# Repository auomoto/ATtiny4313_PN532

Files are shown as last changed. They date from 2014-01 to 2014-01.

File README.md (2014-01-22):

ATtiny4313_PN532
================
This program controls an Adafruit PN532 RFID/NFC Shield v1.3 from an ATtiny4313.

The target operation is automated filter identification in a telescope filter wheel. Filter holders will have MiFare Classic tags permanently attached. The tags will hold filter identification information.

Ordered three more PN532 shields from Adafruit, 2014-01-16/au
Added ADM1490 (2X) to the schematic for the RS422 serial signal

To-do:
- [ ] Add second controller
- [ ] Add RS-422 transceiver and tie the handshaking lines
- [x] Purchase magnetic sheet for shielding
- [x] Build board holder
- [ ] Build SMD board

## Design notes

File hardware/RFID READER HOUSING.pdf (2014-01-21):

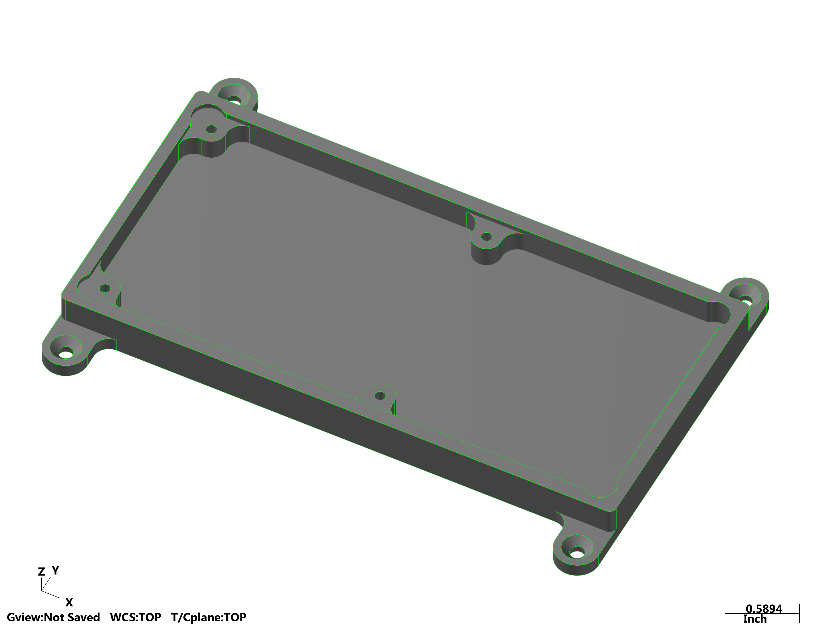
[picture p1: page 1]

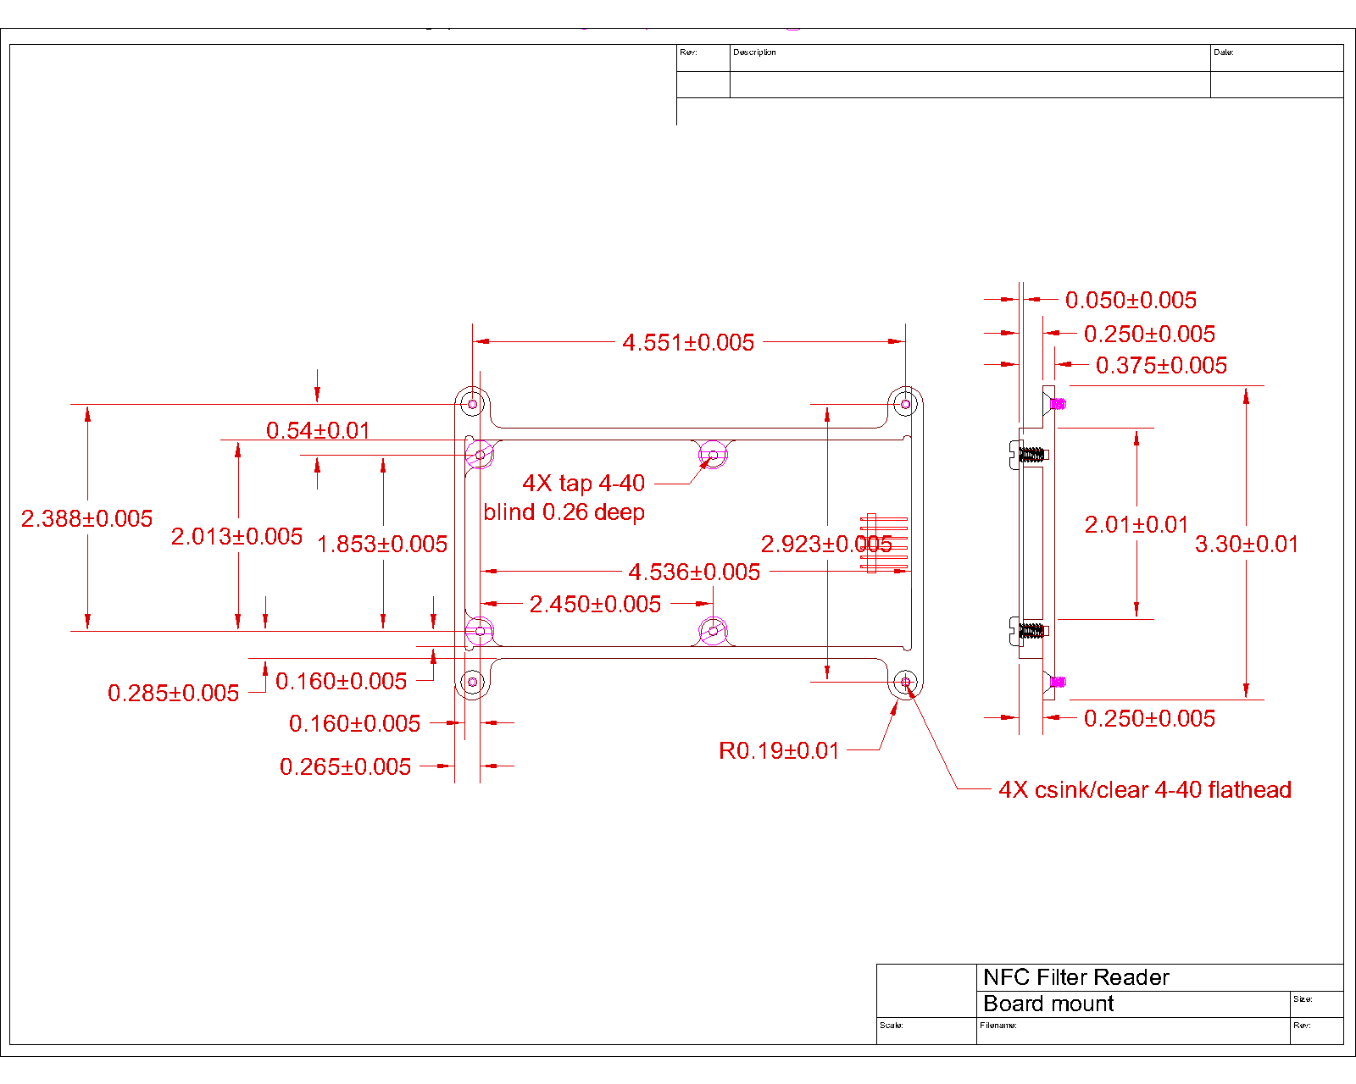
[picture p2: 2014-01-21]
hardware/ATtiny4313_PN532_BoardMount.png

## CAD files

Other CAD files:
hardware/ATtiny4313_PN532_BoardMount.dwg

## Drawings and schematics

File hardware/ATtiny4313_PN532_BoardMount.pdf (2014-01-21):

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

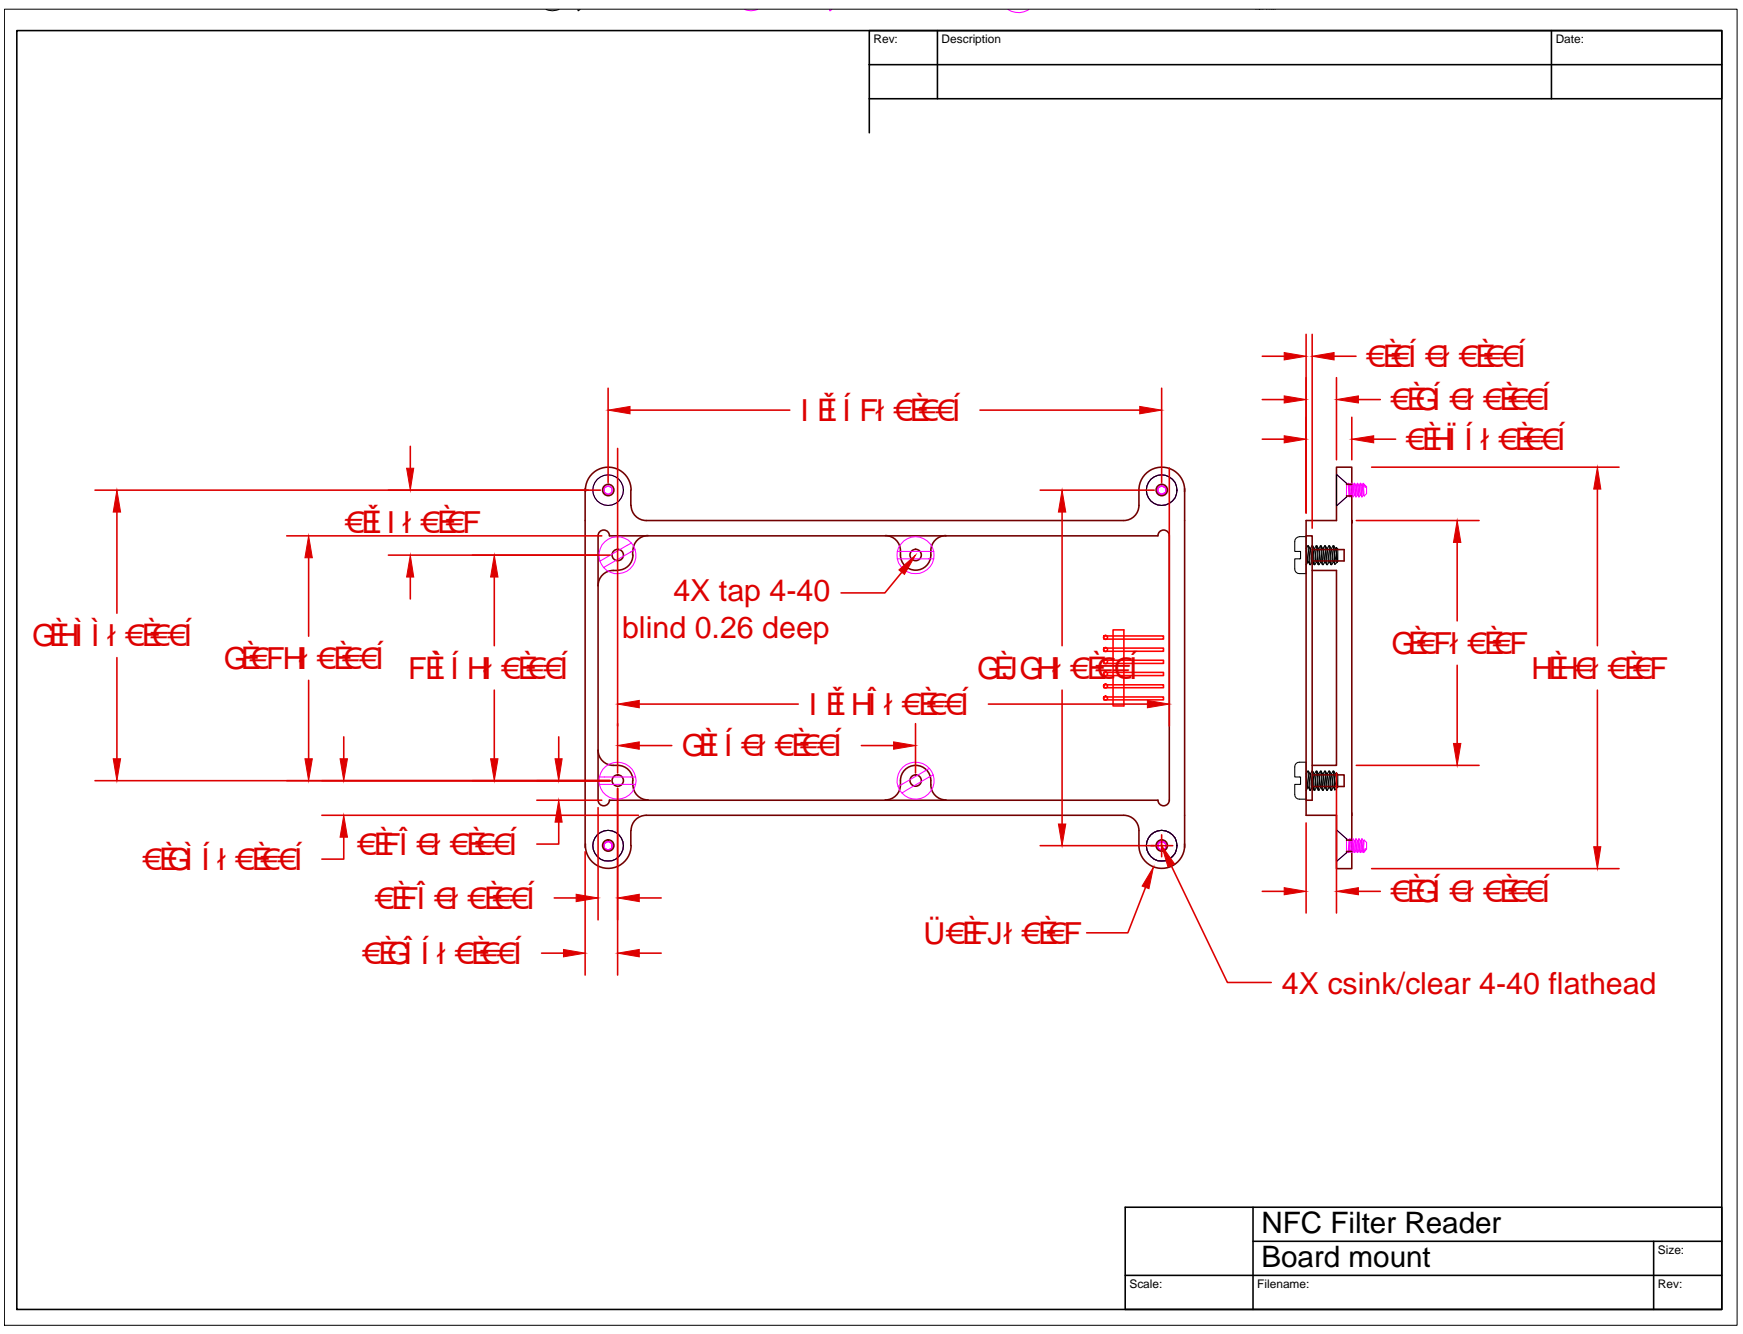
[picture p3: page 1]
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

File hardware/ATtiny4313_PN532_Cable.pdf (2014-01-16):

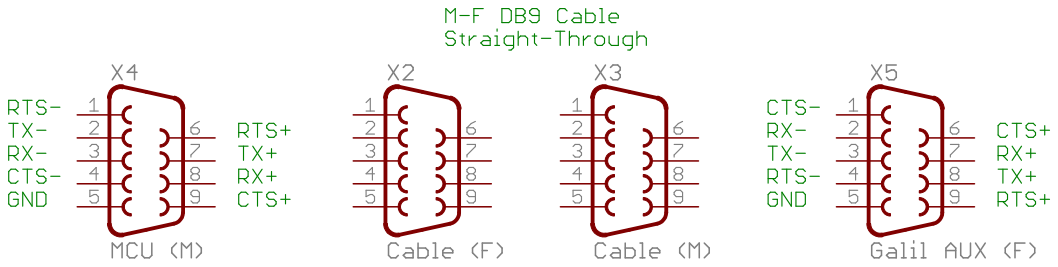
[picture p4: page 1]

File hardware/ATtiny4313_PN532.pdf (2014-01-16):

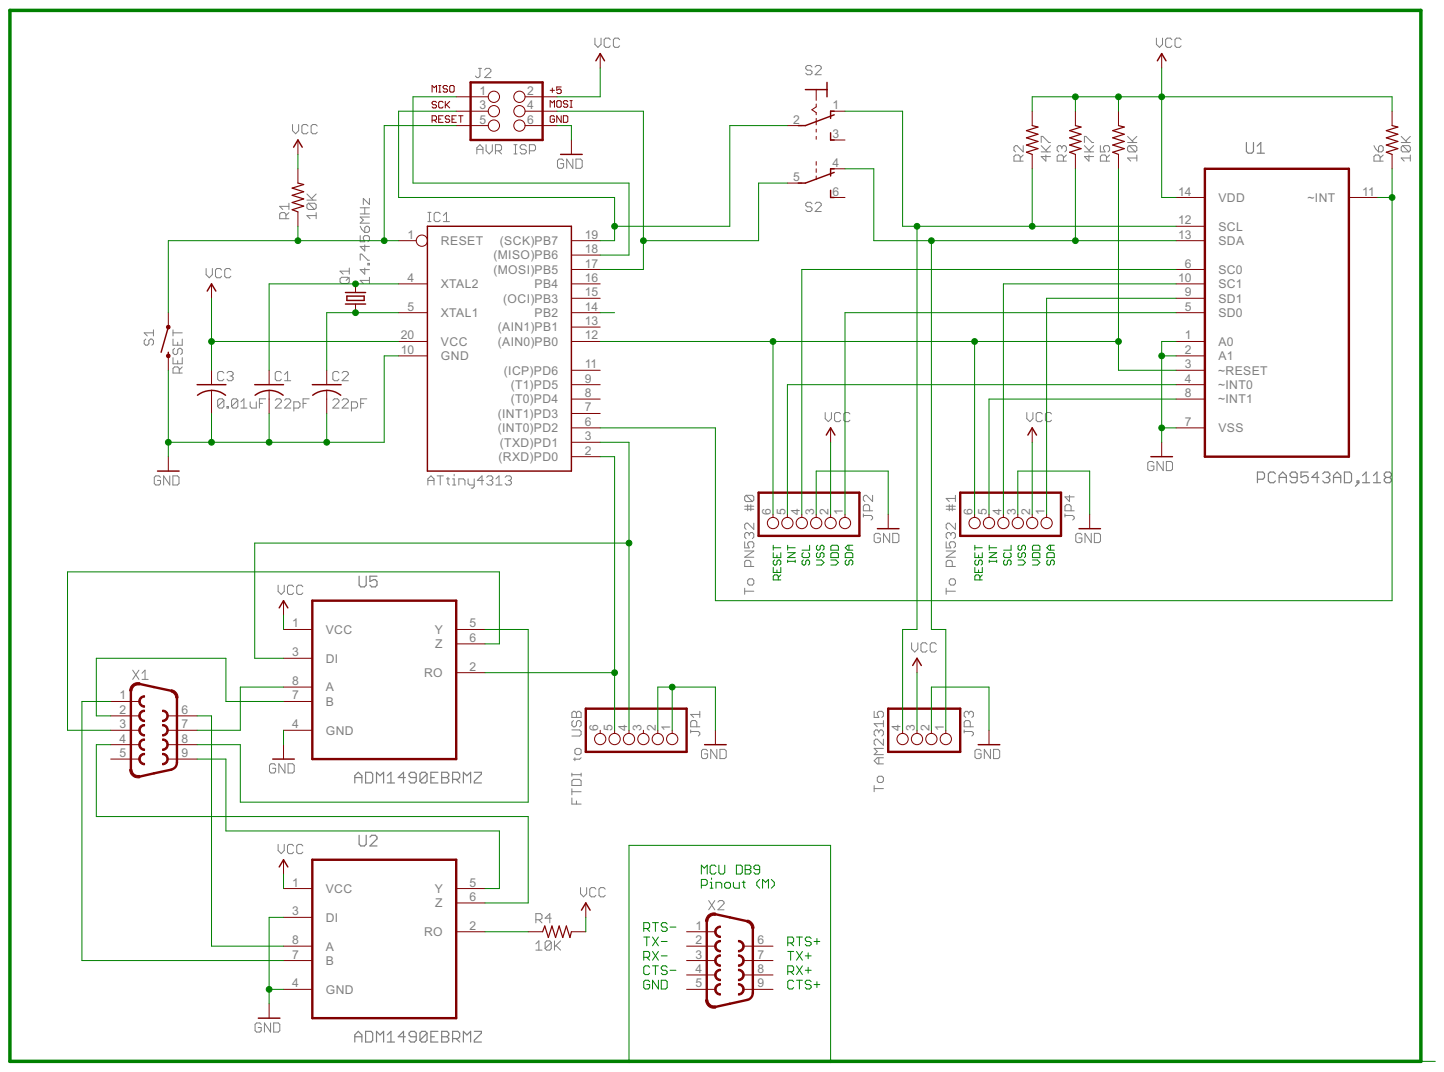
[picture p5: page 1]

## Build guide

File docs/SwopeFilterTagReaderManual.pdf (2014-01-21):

# Swope Filter Tag Reader

## Revisions

Rev | Date | Notes
1.0 | 2014-01-09 | Initial release (au)
1.1 | 2014-01-21 | Added ADM1490 RS-422 transceiver information & more links

## Summary

The Filter Tag Reader reads data from near field communications (NFC) tags. For tags mounted on filter holders this information can identify filter wheel contents. It can also write to the NFC tag.

## Software

Communications is through an RS-422 serial port on the Galil DMC 4080 controller on the Swope IMB. The setup is 19,200 baud, 8-bits, no parity, one stop bit. There is no flow control; the Galil handshaking lines (RTS and CTS) are tied.
Commands sent to the tag reader are one-byte ASCII characters as described below. The command character is echoed. If the command is not ‘w’ then the echoed command character is followed by “\r\n”. If there is returned information (the tag data, status information, or an error code) that information is sent and followed by another “\r\n”. Finally the prompt character ‘>’ is sent.

### Commands

Command | Name | Details
0 or 1 | Select wheel | These are ASCII characters 0 (numeral zero, not oh) and 1 (numeral one, not ell). Subsequent commands will reference the selected filter wheel, 0 or 1.
i | Tag ID | Prints the 32-bit MiFare tag ID in hex. This probably isn’t a useful number to know but if a reply is returned you know it’s a MiFare Classic tag.
r | Read tag | If a tag is present 32 bytes are returned. A brand-new blank tag will likely contain zeros (0x00, not the ASCII numeral). For prepared tags, an end-of-string byte (\0) is not necessarily included in the 32 bytes.
R | Reset | Reboots the microcontroller and resets the hardware. Total time should be less than one second and you’ll see a “WD\r\n>” returned. The “WD” refers to a watchdog reset, which can happen only with this command (the watchdog timer is disabled except for this reset function). The input stream to the tag reader is cleared on reboot so commands sent immediately following the “R” and before the WD response will be lost.
s | status | Prints system status information. In order, the returned items are the program name (“FIlter_Reader”), this software version number (yyyymmdd), firmware version of the selected tag reader (if it’s “X.X” and not “1.6” then no tag reader is present), and the contents of the program status byte. Bit 0 of the status byte shows the currently selected wheel number (0 or 1). The other seven bytes are program error codes. If they’re not all zeros (that is, if the status byte is not 0x00 or 0x01), you should probably try a read command (‘r’) or do a reset (‘R’ command)..
w | Write tag | This command writes the following 32 bytes to the tag. A carriage return (\r) terminates data entry if you have fewer than 32 bytes to write. The \r will not be included in the 32 bytes. The remainder of the 32 bytes will be padded with spaces (‘ ‘ or 0x20). Example: wH-Beta Filter\r will write “H-beta Filter” padded with spaces into the tag.
\r (CR) | No-op | Sending a carriage return will return the command prompt string “\r\n>”

### Errors

The tag reader may reply with an error code. The error code format is “\r\nENN\r\n>” where NN are ASCII numerals as described below. Note that the “\r\n>” sequence right after ENN distinguishes this from a read-back of valid tag data which always returns 32 bytes. Except for errors 10, 11, and 99, you’ll need to look at the firmware source code for why the problem occurred.

Code | Meaning
E99 | Not a command (the byte sent was not recognized as a command)
E10 | No tag or an unrecognized tag at wheel 0
E11 | No tag or an unrecognized tag at wheel 1
E20 | Problem writing to tag on wheel 0
E21 | Problem writing to tag on wheel 1
E80 | Initialization error on tag reader for wheel 0
E81 | Initialization error on tag reader for wheel 1

### Reboot transmissions

The tag reader will send these messages without being commanded. All of these happen after a reboot and all are followed by a “\r\n>” sequence.

Message | Meaning
BO | Reboot after power brown-out (supply voltage under 2.7VDC)
PB | Pushbutton reset (the button on the MCU hardware was pushed)
PU | Power up start
WD | Watchdog reset (only happens with the R command)

## Firmware

### Source Code

The firmware source code resides in a GitHub repository. (https://github.com/auomoto/ATtiny4313_PN532) The program is for an Atmel ATtiny4313, compiles under avr-gcc (Windows version), and uses avr-gcc specific macros.

### Status Register

The contents of an 8-bit status register is the last item printed on a status command (letter s). Bit 0 of this byte contains the current selected filter wheel (from the 0 or 1 commands). The other seven bits contain error codes that we expect only rarely. These might be caused by a hardware failure, loose wire connection, or a bad tag. If any of bits 1-7 are not zero, try a Reset (‘R’) command to see if that clears the condition. These can be confusing in the sense that you cannot tell which tag reader (or both) caused the error.

Bit 0 - Indicates which filter wheel reader is connected.
Bit 1 - recvAck error. The reader did not send an ACK frame after a command.
Bit 2 - Firmware version error. The reader firmware wasn’t read or is wrong.
Bit 3 - authenticateBlock error. The password for the block is not 0xFFFFFFFFFFFF. Bit 4 - readBlock error. A problem reading one or both data blocks.
Bit 5 - writeBlock error. A problem writing a block.
Bit 6 - sendCmdAck error. A command transmission / reception error.
Bit 7 - init_pn531 error. Initialization (samconfig or rfconfig error).

## Hardware

### Tags

We use Mifare (http://en.wikipedia.org/wiki/MIFARE) Classic 13.56 MHz tags. They have a few hundred bytes of usable storage memory although we’re only using 32 bytes and come in a wide variety of shapes, sizes, and colors. Because our filter frames are made of aluminum, we need to use “anti-metal” tags, which have a ferrous layer isolating the tag from the underlying aluminum.
You should get unformatted tags (not preformatted NDEF tags).
These tags come from the factory with authentication key (password) of 0xFFFFFFFFFFFF and we do not change this.

### Tag reader

The NFC tag reader controller is the NXP PN532 chip. (http://www.nxp.com/products/interface_and_connectivity/nfc_contactless_reader_ics/PN5321A3HN.html) We chose an Adafruit-branded “shield” (https://www.adafruit.com/products/789) version of the microBuilder board. (http://www.microbuilder.eu/Projects/PN532) This board has a built-in antenna and runs on 5 VDC.

The PN532 can communicate via SPI, I2C, or serial interfaces. We chose I2C (TWI). In retrospect, it might’ve been easier to use SPI for this project since the PN532 has only one fixed I2C address option, which makes using two of them more difficult.

### MCU

The MCU is an Atmel ATtiny4313. (http://www.atmel.com/images/doc8246.pdf) This chip has a hardware UART for serial communications to the Galil controller. We’re using a 14.7456 MHz crystal that allows us to choose common serial baud rates.

### Bus switch

Since all PN532 boards have identical I2C addresses we will use the PCA9543AD (http://www.nxp.com/documents/data_sheet/PCA9543A_43B_43C.pdf) I2C bus switch to select which of the two boards we want.

### RS-422 conversion

To convert the RS-422 signals on the Galil controller to TTL serial levels, we’ll use two ADM1490 (http://www.analog.com/en/interface-isolation/rs-485-rs-422/adm1490e/products/product.html) transceivers. Each ADM1490 has one transmitter and one receiver. We need two because the Galil RS-422 interface requires hardware handshaking with the RTS and CTS signals as well as data receive and transmit.

## Glossary

Item | Description
I2C | Inter-Integrated Circuit bus
IMB | Instrument Mounting Base (Carnegie Observatories notation)
MCU | MicroController Unit
NDEF | NFC Data Exchange Format
NFC | Near Field Communications
SPI | Serial Peripheral Interface
TTL | Transistor-Transistor Logic
TWI | Two-Wire Interface, similar to I2C, functionally equivalent
UART | Universal asynchronous receiver/transmitter

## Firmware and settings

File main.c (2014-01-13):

/*

	Check fuses:

	>avrdude -c usbtiny -p ATtiny4313 -P usb -U lfuse:r:-:h

	Burned new fuses: 0xFF 0xDF 0xFF
	>avrdude -p ATtiny4313 -c usbtiny -U lfuse:w:0xff:m
	The 0xFF in lfuse gives the longest startup time with a crystal

	Using a 14.745600 MHz crystal (edit the Makefile).

	Writing the version name (in eeVer) to eeprom:

	avrdude -c usbtiny -p ATtiny4313 -P usb -U eeprom:w:main.eep:i

	Do this AFTER you've programmed the flash memory.

	But I've edited the Makefile to do this automatically.

*/

//#define PN532DEBUG
#include <stdlib.h>						// for atoi()
#include <string.h>						// for memset()
#include <util/delay.h>					// AVR/GCC delay routines
#include <avr/io.h>
#include <avr/wdt.h>
#include <avr/eeprom.h>
#include "usi_twi_master.h"
#include "pca9543.h"
#include "PN532_twi.h"

#define RESETPIN PB0					// Connect to reset pin on PN532 board
#define LEDPIN PB2						// PB2 is the pin for OC0A
#define brightness(X) (OCR0A = X)		// PWM on PB2

#define CHARSENT (UCSRA & _BV(RXC))		// Is there something in the RX buffer?
#define TXREADY (UCSRA & _BV(UDRE))		// Is the transmit buffer empty?

#ifndef TRUE
#define TRUE	1
#define FALSE	0
#endif

uint8_t EEMEM eeVer[]="Filter_Reader 20140112";		// be careful of the count

void errMsg(uint8_t);
uint8_t getCardID(uint8_t *, uint8_t*);
static inline void init_ATtiny4313(void);
static inline void init_pn532(uint8_t*);
uint8_t readCard(uint8_t*);
uint16_t recvNum(void);
void sendBlock(uint8_t*, uint8_t);
void sendPrompt(void);
void sendByte(uint8_t);
void sendCRLF(void);
void sendNum(int, uint8_t);
void sendString(char *);
uint8_t writeMiFare(uint8_t*);

int main (void)
{

	uint8_t cmd, frameBuf[36], cardID[5];
	char strBuf[32];

	init_ATtiny4313();
	usi_twi_master_initialize();
	init_pn532(frameBuf);

	sendPrompt();

	for (;;) {
		if (CHARSENT) {
brightness(255);
_delay_ms(25);
brightness(0);
			cmd = UDR;
			sendByte(cmd);

			switch(cmd) {

				case ('R'):					// Software reset
					wdt_enable(WDTO_60MS);
					while (1) {};
					break;

				case ('+'):
					brightness(255);
					break;

				case ('-'):
					brightness(0);
					break;

				case ('i'):
					if (! getCardID(cardID, frameBuf)) {
						errMsg(10 + (GPIOR0 &= 0x01));
					}
					break;
					
				case ('r'):					// Read the first two blocks from the tag under wheel 0
					if (! readCard(frameBuf)) {
						errMsg(10 + (GPIOR0 &= 0x01));
					}
					break;

				case ('0'):
					pca9543SelectChannel(0);
					break;

				case ('1'):
					pca9543SelectChannel(1);
					break;

#ifdef DEBUG
				case ('S'):					// Scan the TWI bus for devices
					for (i = 0; i < 255; i++) {
						frameBuf[0] = i;
						usi_twi_master_start();
						if (usi_twi_master_transmit(frameBuf, 1)) {
							sendByte(' ');
							sendNum(i, 16);
							j = 0;
						}
						usi_twi_master_stop();
					}
					break;
#endif
				case ('s'):					// Status
					sendCRLF();
					eeprom_read_block((void*) &strBuf, (const void*) &eeVer, 22);
					strBuf[22] = 0x00;
					sendString(strBuf);
					if (pn532_twi_sendCommand(GETFIRMWAREVERSION, frameBuf, 0)) {
						sendByte(' ');
						sendNum((int) frameBuf[10], 10);
						sendByte('.');
						sendNum((int) frameBuf[11], 10);
					} else {
						sendString(" X.X");
					}
					sendString(" 0x");
					sendNum(GPIOR0, 16);
					break;

				case ('\r'):
					break;

#ifdef DEBUG
				case ('t'):					// a test function
					sendCRLF();
					sendString(":");
					int itest = recvNum();
					sendNum(itest, 10);
					break;
#endif
				case ('w'):			// Write the first two blocks in the MiFare card
					if (! writeMiFare(frameBuf)) {
						errMsg(20 + (GPIOR0 & 0x01));
					}
					break;

				default:
					errMsg(99);
					break;

			}
			sendPrompt();
		}
	}
}

uint8_t getCardID(uint8_t cardID[], uint8_t frameBuf[])
{

	uint8_t i;

	pn532_twi_sendCommand(INLISTPASSIVETARGET, frameBuf, 0);
	if (frameBuf[9]) {
		for (i = 0; i < 4; i++) {
			cardID[i] = frameBuf[i+15];
		}
		sendCRLF();
		for (i = 0; i < 4; i++) {
			sendNum(cardID[i], 16);
		}
	} else {
		return(FALSE);
	}
	return(TRUE);
}

uint8_t readCard(uint8_t frameBuf[])
{

	uint8_t i, cardID[5];

	pn532_twi_sendCommand(INLISTPASSIVETARGET, frameBuf, 0);

	if (frameBuf[9]) {
		for (i = 0; i < 4; i++) {
			cardID[i] = frameBuf[i+15];
		}
		if (pn532_readBlock(cardID, 1, frameBuf)) {
			sendCRLF();
			sendBlock(frameBuf, 10);
		} else {
			return(FALSE);
		}
		if (pn532_readBlock(cardID, 2, frameBuf)) {
			sendBlock(frameBuf, 10);
		} else {
			return(FALSE);
		}
		return(TRUE);
	}
	return(FALSE);
}

void sendBlock(uint8_t frameBuf[], uint8_t base)
{

	uint8_t i;

	if (base == 16) {
		for (i = 0; i < 16; i++) {
			sendNum(frameBuf[i+10], 16);
		}
	} else {
		for (i = 0; i < 16; i++) {
			sendByte(frameBuf[i+10]);
		}
	}

}

uint8_t writeMiFare(uint8_t frameBuf[])
{

	uint8_t cardID[5], buf[32];
	uint8_t i;

	memset(buf, 0x20, 32);
	for (i=0; i<32; i++) {
		while (!CHARSENT) {
		}
		buf[i] = UDR;
		if (buf[i] < 0x20) {	// 0x20 is a space
			buf[i] = ' ';
			break;
		} else {
			sendByte(buf[i]);
		}
	}

	if (! pn532_twi_sendCommand(INLISTPASSIVETARGET, frameBuf, 0)) {
		return(FALSE);
	}
	if (frameBuf[9]) {
		for (i = 0; i < 4; i++) {
			cardID[i] = frameBuf[i+15];
		}
	} else {
		return(FALSE);
	}


	if (! pn532_writeBlock(cardID, 1, buf, frameBuf)) {
		return(FALSE);
	}
	if (! pn532_writeBlock(cardID, 2, &buf[16], frameBuf)) {
		return(FALSE);
	}
	return(TRUE);
}

/*
	recvNum() accepts characters from the serial port and returns the twos complement
	16-bit integer. It echos the characters as they're typed and concludes when a
	carriage return is entered.

	Errors: If more than five (5) characters without sign are entered, or if more
	than six (6) characters with a leading + or - sign are entered, this routine
	sends back a question mark (?), CRLF, and returns zero (0).

*/

uint16_t recvNum(void)
{

	char strBuf[7];
	uint8_t i = 0;

	for (;;) {
		while (!CHARSENT) {
			asm("nop");
		}
		strBuf[i] = UDR;
		sendByte(strBuf[i]);
		if (strBuf[i] == '\r') {
			strBuf[i] = 0x00;
			sendCRLF();
			break;
		}
		if (i == 5) {
			if ((strBuf[0] != '+') && (strBuf[0] != '-')) {
				sendCRLF();
				sendByte('?');
				return(0);
			}
		}
		if (i == 6) {
			sendCRLF();
			sendByte('?');
			return(0);
		}
		i++;
	}

	return(atoi(strBuf));

}

void sendByte(uint8_t x)
{

	while (!TXREADY) {
		asm("nop");
	}

	UDR = x;

}

void sendCRLF(void)
{

	sendByte('\n');
	sendByte('\r');

}

void sendNum(int number, uint8_t base)
{

	char strBuf[7];

	if (base == 16) {
		if (number <= 0x0f) {					// send leading '0' for hex
			sendByte('0');
		}
	}
	sendString(itoa(number, strBuf, base));

}

void sendPrompt(void)
{

	sendCRLF();
	sendByte('>');

}

void sendString(char str[])
{

	uint8_t i = 0;

	while (str[i]) {
		sendByte(str[i++]);
	}

}

/*
	errMsg()
	E99 - bad command
*/

void errMsg(uint8_t msgNum)
{

	sendCRLF();
	sendByte('E');
	sendNum(msgNum, 10);

}

static inline void init_pn532(uint8_t frameBuf[])
{

	uint8_t i;

	for (i = 0; i < 2; i++) {
		pca9543SelectChannel(i);
		if (! pn532_twi_sendCommand(SAMCONFIG, frameBuf, 0)) {
			GPIOR0 |= _BV(INITPN532);
			errMsg(80 + (GPIOR0 & 0x01));
			return;
		}
		if (! pn532_twi_sendCommand(RFCONFIGURATION, frameBuf, 0)) {
			GPIOR0 |= _BV(INITPN532);
			errMsg(80 + (GPIOR0 & 0x01));
			return;
		}
	}
	pca9543SelectChannel(0);

}

/*
===========================================================================

	UBRRL and UBRRH USART Baud Rate Registers. 12 bits, computed from:
	
	UBRR = (F_CPU / (16 * Baudrate)) - 1 where "Baudrate" is the common
	understanding.

===========================================================================

	UCSRB Control STatus Register B
	---------------------------------------------------------------------
	Bit	|	7	|	6	|	5	|	4	|	3	|	2	|	1	|	0	|
	Item| RXCIE	| TXCIE	| UDRIE	|  RXEN	|  TXEN	| UCSZ2	|  RXBB	|  TXBB	|
	Set	|	0	|	0	|	0	|	1	|	1	|	0	|	0	|	0	|
	---------------------------------------------------------------------

	RXCIE is RX Complete Interrupt Enable (we won't use this)
	TXCIE is the TX Complete Interrupt ENable
	UDRIE is USART Data Register Empty Interrupt Enable
	RXEN is Receiver Enable
	TXEN is Transmitter Enable
	UCSZ2, combined with UCSZ[1:0] in UCSRC sets the number of data bits
	RXB8 Receive Data Bit 8 (ninth bit of data, if present)
	TXB8 Transmit bit 8 (ninth bit of data)

	UCSRB = 0b00011000

===========================================================================

	UCSRC Control STatus Register C
	---------------------------------------------------------------------
	Bit	|	7	|	6	|	5	|	4	|	3	|	2	|	1	|	0	|
	Item|UMSEL1	|UMSEL0	| UPM1	| UPM0	| USBS	| UCSZ1	| UCSZ0	| UCPOL	|
	Set	|	0	|	0	|	0	|	0	|	0	|	1	|	1	|	0	|
	---------------------------------------------------------------------

	UMSEL[1:0] is the USART mode select. We want 0b00, Asynchronous UART
	UPM[1:0] is Parity mode. 0b00 is disabled, 0b01 reserved, 0b10 Enabled,
	even parity, 0b11 Enabled, odd parity.
	USBS is Stop Bit Select (how many stop bits). 0->1-bit, 1->2-bits.
	UCSZ[1:0] is the rest of the character size description. An 8-bit
	situation says both of these bits should be high.
	UCPOL is clock polarity. Changes fall/rising edges.

	UCSRC = 0b00000110

===========================================================================

	TCCR0A (Timer/Counter Control Register A for Timer0) settings
	---------------------------------------------------------------------
	Bit	|	7	|	6	|	5	|	4	|	3	|	2	|	1	|	0	|
	Item| COM0A1| COM0A0| COM0B1| COM0B0|	-	|	-	| WGM01	| WGM00	|
	Set	|	1	|	0	|	0	|	0	|	0	|	0	|	0	|	1	|
	---------------------------------------------------------------------

	For phase-correct PWM with TOP=OCR0A, WGM0[2:0] should be 0b001 (WGM0[2]
	is in TCCR0B). In phase correct PWM mode the timer counts up, then down.

	We're only using one compare register here so COM0B[1:0] is 0b00 and
	COM0A[1:0] is 0b10, which sets OC0A on the way up and clears it on the
	way down.

	TCCR0A = 0b10000001

===========================================================================

	TCCR0B (Timer/Counter Control Register B for Timer0) settings
	---------------------------------------------------------------------
	Bit	|	7	|	6	|	5	|	4	|	3	|	2	|	1	|	0	|
	Item| FOC0A	| FOC0B	|	-	|	-	| WGM02	|  CS02	|  CS01	|  CS00	|
	Set	|	0	|	0	|	0	|	0	|	0	|	0	|	1	|	0	|
	---------------------------------------------------------------------

	CS0[2:0] are the clock select bits:

		0b000	No clock source (timer stopped)
		0b001	clk/1 (no prescaling)
		0b010	clk/8
		0b011	clk/64
		0b100	clk/256
		0b101	clk/1024
		0b110	External clock on T0 pin, falling edge
		0b111	External clock on T0 pin, rising edge

	The PWM frequency is clk/(N*510) where N is the prescale factor. If
	our nominal CPU clock frequency is 14.745600 MHz, the frequency and
	period for the prescaled timer are are:

		======================================
		CS0[2:0]	Frequency		Period
		--------------------------------------
		0b001		28.913 kHz		 34.6 us
		0b010		 3.614 kHz		276.7 us
		0b011	   452.765 Hz		  2.214 ms
		0b100	   112.941 Hz		  8.854 ms
		0b101	    28.235 Hz		 35.417 ms
		======================================

	The Faulhaber 2622 B-SC motor takes a PWM frequency input in the range
	of 500 Hz to 18 kHz. Let's choose 3.614 kHz. The motor stops turning at
	duty cycle < 2.0% (5/255) and starts turning at duty cycle > 3.0% (8/255).

	For phase-correct PWM, WGM0[2:0] (Wavform Generation Mode)
	should be 0b001 if we're using OC0A (setting WGM0[2] to "1" means that
	OC0A becomes TOP and OC0B is the compared register). WGM0[1:0] are in
	TCCR0A.

	The Force Output Compare (FOC0A and FOC0B bits) must be set to zero (0)
	when using the timer in PWM mode.

	TCCR0B = 0b00000010

===========================================================================

	MCUSR MCU Status Register (what caused the MCU Reset?)
	---------------------------------------------------------------------
	Bit	|	7	|	6	|	5	|	4	|	3	|	2	|	1	|	0	|
	Item|   -	|   -	|	-	|	-	| WDRF	|  BORF	| EXTRF	|  PORF	|
	Set	|	0	|	0	|	0	|	0	|	0	|	0	|	1	|	0	|
	---------------------------------------------------------------------

	WDRF: Watchdog Reset Flag is set if a WD Reset occurs. Reset by power
	on or writing zero to the flag.
	
	BORF: Brown-out Reset flag is set if a brown-out Reset happens.
	
	EXTRF: External Reset Flag
	
	PORF: Power-on Reset Flag

	NB: THe WDRF *MUST* be reset or the system will immediately reset and
	loop forever.

===========================================================================

	WDTCR Watchdog Timer Control Register (aka WDTCSR on ATtiny2313)
	128kHz oscillator
	---------------------------------------------------------------------
	Bit	|	7	|	6	|	5	|	4	|	3	|	2	|	1	|	0	|
	Item| WDIF	| WDIE	| WDP3	| WDCE	|  WDE	| WDP2	| WDP1	|  WDP0	|
	Set	|	0	|	0	|	0	|	0	|	0	|	0	|	1	|	0	|
	---------------------------------------------------------------------

	WDIF: Watchdog Timeout Interrupt Flag is set when a timeout occurs
	and the WDT is configured for interrupt.
	WDIE: Watchdog Timeout Interrupt Enable.
	WDP3: One of three prescaler bits (see below)
	WDCE: Watchdog Change Enable (must be set to change WDE)
	WDE: Watchdog enable
	WDP[3:0]: Timer prescaler bits

		=========================================
		WDP3	WDP2	WDP1	WDP0	Appx time
		-----------------------------------------
		 0		 0		 0		 0		16 ms
		 0		 0		 0		 1		32 ms
		 0		 0		 1		 0		64 ms
		 0		 0		 1		 1		0.125 s
		 0		 1		 0		 0		0.25 s
		 0		 1		 0		 1		0.5 s
		 0		 1		 1		 0		1.0 s
		 0		 1		 1		 1		2.0 s
		 1		 0		 0		 0		4.0 s
		 1		 0		 0		 1		8.0 s
		=========================================

	Recovering from a WDT reset is a little tricky. The steps:
		1. Clear the MCUSR watchdog reset flag (WDRF).
		2. In one operation, write logic one to both WDCE and WDE.
		3. In the very next line, write a logic 0 to WDE.


===========================================================================

*/

#define BAUDRATE 19200
#define MYUBRR ((F_CPU / 16 / BAUDRATE) -1)
#define WATCHDOG	1
#define POWERON		2
#define PUSHBUTTON	3
#define BROWNOUT	4

static inline void init_ATtiny4313(void)
{

	uint8_t junk, resetType = 0;

								// Handle watchdog reset
	if (MCUSR & _BV(WDRF)) {	// If there was a watchdog reset...
		MCUSR = 0x00;			// Clear the WDRF flag (and everything else)
		WDTCR = 0x18;			// WDCE must be high to change WDE (WDEnable)
		WDTCR = 0x00;			// Now clear WDE
		resetType = WATCHDOG;
	} else if (MCUSR & _BV(PORF)) {
		resetType = POWERON;
	} else if (MCUSR & _BV(EXTRF)) {
		resetType = PUSHBUTTON;
	} else if (MCUSR & _BV(BORF)) {
		resetType = BROWNOUT;
	}
	MCUSR = 0x00;

	UBRRH = (uint8_t) (MYUBRR >> 8);	// Set baud rate
	UBRRL = (uint8_t) MYUBRR;
	UCSRB = 0b00011000;					// Enable transmit & receive
	UCSRC = 0b00000110;					// 8 data bits, no parity, one stop bit

										// PWM output for LED (don't need this)
	TCCR0A = 0b10000001;				// Phase-correct PWM on OC0A (see above)
	TCCR0B = 0b00000010;				// Select clock prescaler /8 (see above)


	while (CHARSENT) {					// Clear the serial port
		junk = UDR;
	}

	PORTB |= _BV(RESETPIN);
	DDRB |= _BV(RESETPIN);
	DDRB |= _BV(LEDPIN);				// LEDPIN is an output
	PORTD |= _BV(INTPIN);				// Pullup on interrupt pin
	PORTB &= ~_BV(RESETPIN);			// Reset everything
	_delay_us(1);
	PORTB |= _BV(RESETPIN);
	brightness(255);					// Flash the light (alive indication & reset wait)
	_delay_ms(100);
	brightness(0);
	DDRB &= ~_BV(RESETPIN);			// Tri-state
	PORTB &= ~_BV(RESETPIN);

	switch (resetType) {
		case (WATCHDOG):
			sendString("WD");
			break;
		case (BROWNOUT):
			sendString("BO");
			break;
		case (POWERON):
			sendString("PU");
			break;
		case (PUSHBUTTON):
			sendString("PB");
			break;
		default:
			break;
	}

}

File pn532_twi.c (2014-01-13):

#include "usi_twi_master.h"
#include "pn532_twi.h"
#include "pca9543.h"

uint8_t pn532_authenticateBlock(uint8_t cardID[], uint8_t blockNum, uint8_t frameBuf[])

{
	uint8_t i, len, command[15];

	command[0] = INDATAEXCHANGE;
	command[1] = 0x01;				// Target number
	command[2] = AUTHENTICATE_A;	// MiFare card key "A"
	command[3] = blockNum;
	for (i = 0; i < 6; i++) {
		command[4+i] = 0xFF;		// Authenticate key A
	}
	for (i = 0; i < 4; i++) {
		command[10+i] = cardID[i];
	}
	len = pn532_buildFrame(15, command, frameBuf);
	if (pn532_twi_sendCmdAck(frameBuf, len) == FALSE) {
		GPIOR0 |= _BV(AUTHBLK);
		return(FALSE);
	}
	while (pn532_notReady()) {
	}
	frameBuf[0] = 0x49;
	usi_twi_master_start();
	usi_twi_master_receive(frameBuf, 14);
	usi_twi_master_stop();
	if (frameBuf[9]) {
		GPIOR0 |= _BV(AUTHBLK);
		return(FALSE);
	}
	GPIOR0 &= ~_BV(AUTHBLK);
	return(TRUE);

}

uint8_t pn532_readBlock(uint8_t cardID[], uint8_t blockNum, uint8_t frameBuf[])
{

	uint8_t len, command[4];

	if (pn532_authenticateBlock(cardID, blockNum, frameBuf) == FALSE) {
		return(FALSE);
	}
	command[0] = INDATAEXCHANGE;
	command[1] = 0x01;				// Target number
	command[2] = READBLOCK;			// MiFare card key read 16 bytes
	command[3] = blockNum;
	len = pn532_buildFrame(5, command, frameBuf);
	if (pn532_twi_sendCmdAck(frameBuf, len) == FALSE) {
		GPIOR0 |= _BV(READBLK);
		return(FALSE);
	}
	while (pn532_notReady()) {
	}
	frameBuf[0] = 0x49;
	usi_twi_master_start();
	usi_twi_master_receive(frameBuf, 26);
	usi_twi_master_stop();
	if (frameBuf[9] != 0x00) {
		GPIOR0 |= _BV(READBLK);
		return(FALSE);
	} else {
		GPIOR0 &= ~_BV(READBLK);
		return(TRUE);
	}
}

uint8_t pn532_writeBlock(uint8_t cardID[], uint8_t blockNum, uint8_t data[], uint8_t frameBuf[])
{

	uint8_t i, len, command[25];

	if (pn532_authenticateBlock(cardID, blockNum, frameBuf) == FALSE) {
		GPIOR0 |= _BV(WRITEBLK);
		return(FALSE);
	}
	command[0] = INDATAEXCHANGE;
	command[1] = 0x01;				// Target number
	command[2] = WRITEBLOCK;		// MiFare card key write 16 bytes
	command[3] = blockNum;
	for (i = 0; i < 16; i++) {
		command[i+4] = data[i];
	}
	len = pn532_buildFrame(21, command, frameBuf);
	if (pn532_twi_sendCmdAck(frameBuf, len) == FALSE) {
		GPIOR0 |= _BV(WRITEBLK);
		return(FALSE);
	}

	while (pn532_notReady()) {
	}
	frameBuf[0] = 0x49;
	usi_twi_master_start();
	usi_twi_master_receive(frameBuf, 29);
	usi_twi_master_stop();
	if (frameBuf[9] != 0x00) {
		GPIOR0 |= _BV(WRITEBLK);
		return(FALSE);
	} else {
		GPIOR0 &= ~_BV(WRITEBLK);
		return(TRUE);
	}

}

/*

	Build a pn532 command frame. Does not read or write to the TWI bus.

	len is the command length, the count of tfi byte + command byte + data.

	command[] contains the command (zeroth byte) and following data.

	framebuf[] is the returned command array. framebuf[0] is always 0x48,
	the PN532 write address. If you want a read, add 1 (one) to framebuf[0]
	after this to set the read bit (but this never happens?).
	
	Returns the length of framebuf[].

*/
uint8_t pn532_buildFrame(uint8_t len, uint8_t command[], uint8_t framebuf[])
{

	uint8_t i, j;
	uint16_t temp;

	framebuf[0] = 0x48;						// pn532 address (write)
	framebuf[1] = 0x00;						// preamble
	framebuf[2] = 0x00;						// start of frame
	framebuf[3] = 0xff;						// start of frame
	framebuf[4] = len;						// commmand length
	framebuf[5] = ~len + 1;					// lcs (packet length checksum)
	framebuf[6] = 0xd4;						// tfi (frame identifier)
	temp = 0xd4;							// build the data checksum
	j = 7;
	for (i = 0; i < len-1; i++) {
		temp += command[i];
		framebuf[j++] = command[i];
	}
	framebuf[j++] = ~(temp & 0xff) + 1;	// dcs
	framebuf[j++] = 0x00;					// postamble
	return(j);

}

/*

	Puts a PN532 command on the TWI bus. This always initiates a start
	condition and always ends with a stop condition.

	cmd is the PN532 command. This routine knows the data required for
	each command.

	framebuf[] is a scratch array supplied by the calling routine.

	Returns FALSE if the PN532 does not ACK, either in the TWI sense
	or the PN532 sense. Returns FALSE if the command isn't available.

*/

uint8_t pn532_twi_sendCommand(uint8_t cmd, uint8_t frameBuf[], uint8_t blockNum)
{

	uint8_t firmwareVersion[] = {0x49, 0x01, 0x00, 0x00, 0xFF, 0x06, 0xFA, 0xD5, 0x03, 0x32, 0x01, 0x06, 0x07, 0xE8, 0x00};
	uint8_t i, frameLen, command[24];

	switch (cmd) {
	
		case (GETFIRMWAREVERSION):
			command[0] = GETFIRMWAREVERSION;
			frameLen = pn532_buildFrame(2, command, frameBuf);
			if (pn532_twi_sendCmdAck(frameBuf, frameLen) == FALSE) {
				return(FALSE);
			}

			while (pn532_notReady()) {
			}
			frameBuf[0] = 0x49;
			usi_twi_master_start();
			usi_twi_master_receive(frameBuf, 15);
			usi_twi_master_stop();

			for (i = 0; i < 15; i++) {
				if (firmwareVersion[i] != frameBuf[i]) {
					return(FALSE);
				}

			}

			break;
			
		case (SAMCONFIG):
			command[0] = SAMCONFIG;
			command[1] = 0x01;
			frameLen = pn532_buildFrame(3, command, frameBuf);

			if (pn532_twi_sendCmdAck(frameBuf, frameLen) == FALSE) {
				return(FALSE);
			}
			while (pn532_notReady()) {
			}
			frameBuf[0] = 0x49;
			usi_twi_master_start();
			usi_twi_master_receive(frameBuf, 11);
			usi_twi_master_stop();

			break;

		case (INLISTPASSIVETARGET):
			command[0] = INLISTPASSIVETARGET;
			command[1] = 0x01;		// MaxTg maximum # cards
			command[2] = 0x00;		// baud rate code; 0 -> Type A card
			frameLen = pn532_buildFrame(4, command, frameBuf);
			if (pn532_twi_sendCmdAck(frameBuf, frameLen) == FALSE) {
				return(FALSE);
			}
			while (pn532_notReady()) {
			}
			frameBuf[0] = 0x49;
			usi_twi_master_start();
			usi_twi_master_receive(frameBuf, 21);
			usi_twi_master_stop();
			break;

		case (RFCONFIGURATION):		// to set max retries
			command[0] = 0x32;
			command[1] = 0x05;
			command[2] = 0xFF;
			command[3] = 0x01;
			command[4] = 0x01;		// MxRtyPassiveActivation
			frameLen = pn532_buildFrame(6, command, frameBuf);
			if (pn532_twi_sendCmdAck(frameBuf, frameLen) == FALSE) {
				return(FALSE);
			}
			while (pn532_notReady()) {
			}
			frameBuf[0] = 0x049;
			usi_twi_master_start();
			usi_twi_master_receive(frameBuf, 21);
			usi_twi_master_stop();
			break;

		default:
			return (FALSE);

	}
	return(TRUE);
}


uint8_t pn532_twi_sendCmdAck(uint8_t frameBuf[], uint8_t frameLen)
{

	usi_twi_master_start();

	if (usi_twi_master_transmit(frameBuf, frameLen) == FALSE) {
		usi_twi_master_stop();
		GPIOR0 |= _BV(SENDCMDACK);
		return(FALSE);
	}
	usi_twi_master_stop();

	if (pn532_recvAck(frameBuf) == FALSE) {
		GPIOR0 |= _BV(SENDCMDACK);
		return(FALSE);
	}

	GPIOR0 &= ~_BV(SENDCMDACK);
	return(TRUE);
}

/*

	Receives and verifies the PN532 acknowledge frame.
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

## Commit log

2013-12-30 Separated block read and card ID printouts
2014-01-07 Added LTC490 RS485 line drivers to the schematic.
    [ATtiny4313_PN532.sch]
2014-01-07 Added I2C interface board (for prototypes)
    [ATtiny4313_PN532.sch, ATtiny4313_PN532_I2CMUX.sch]
2014-01-09 Added 0 and 1 commands (for two wheels)
2014-01-09 Added pca9543 library routines (I2C switch)
2014-01-09 Added PDF schematic versions
2014-01-12 Added routine to return control register
    [ATtiny4313_PN532_I2CMUX.sch]
2014-01-13 Implemented PCA9543 I2C switch.
2014-01-13 Worked out interrupt procedure for dual cards.
2014-01-13 Mods for checking interrupts (which card?)
2014-01-13 Connected PCA9543 to reset to match the hardware
    [ATtiny4313_PN532.sch]
2014-01-14 Corrected INT wiring
    [ATtiny4313_PN532.sch]
2014-01-15 Corrected wiring to LED and cleaned up a bit
    [ATtiny4313_PN532.sch, ATtiny4313_PNC532_BoardMount.dwg]
2014-01-15 Initial commit; board mount.
    [ATtiny4313_PNC532_BoardMount.dwg]
2014-01-16 Dimensioned PN532 shield mounting Rev0
2014-01-16 Added SCL/SDA isolation switch for programming
2014-01-16 Added SDA/SCL isolation switch for programming
    [ATtiny4313_PN532.sch]
2014-01-16 Rev0 of PN532 shield board mount
    [ATtiny4313_PNC532_BoardMount.dwg]
2014-01-16 Swapped in ADM1490 RS422 xcvr, removed led
    [ATtiny4313_PN532.sch]
2014-01-16 Updated layout page.
    [ATtiny4313_PN532_BoardMount.dwg, ATtiny4313_PNC532_BoardMount.dwg]
2014-01-16 DB9 cable for RS422 signals from Galil 4080
    [ATtiny4313_PN532_Cable.sch]
2014-01-21 Updated drawing and 3d rendering
    [ATtiny4313_PN532_BoardMount.dwg]
2014-01-21 PNG version of board mount drawing
